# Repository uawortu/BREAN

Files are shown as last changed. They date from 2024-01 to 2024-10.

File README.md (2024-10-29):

# BREAN
## Custom esp32cam
Video : [I made a CUSTOM ESP32CAM！ - YouTube](https://www.youtube.com/watch?v=4ouxIVEyoTg)

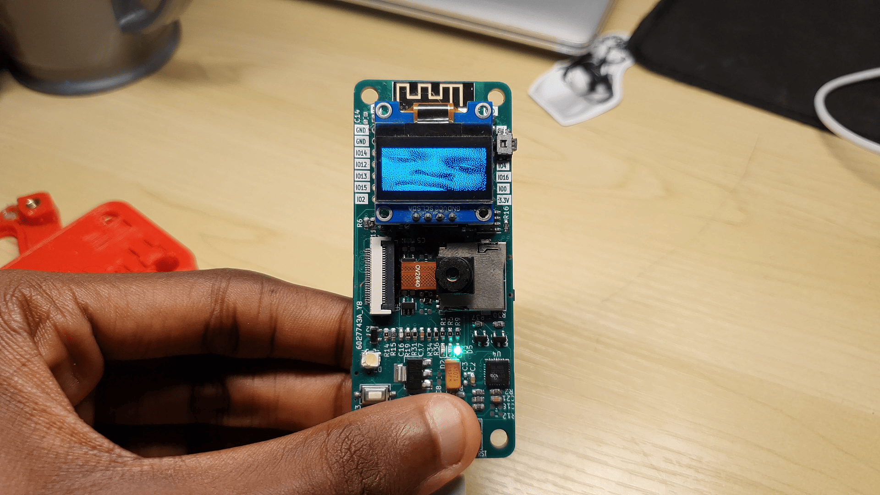
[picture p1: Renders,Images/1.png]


### Information provided
* 3dmodels
* Images and renders
* Gerber files
* My code and code used
* Print files
  
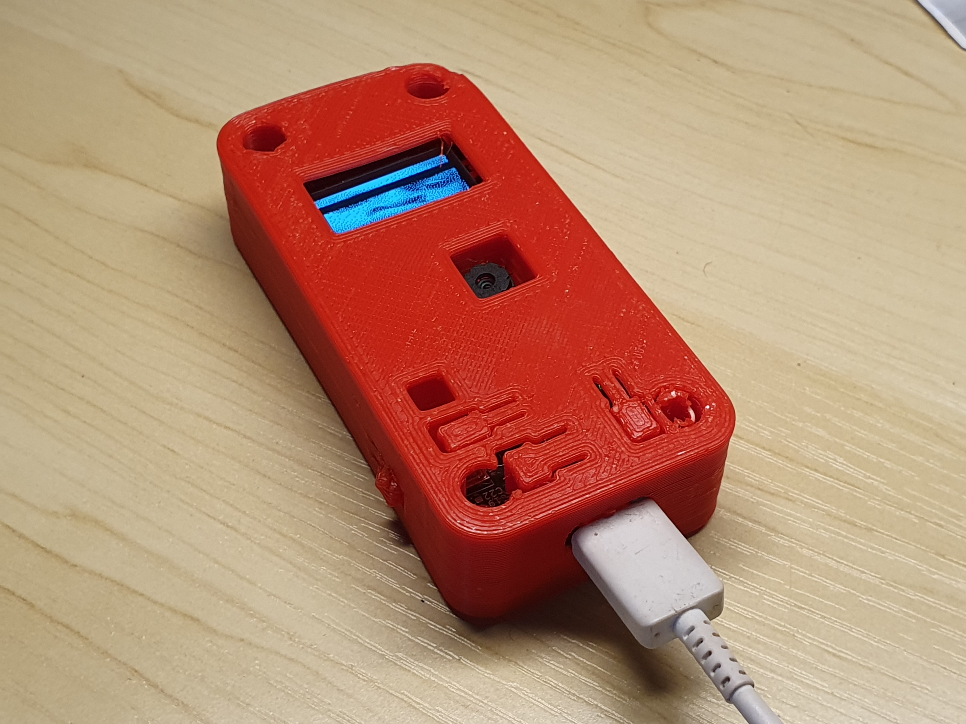
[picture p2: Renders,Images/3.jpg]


# I'll give a proper description in time

#### BOM/PART LIST 
[Google sheets](https://docs.google.com/spreadsheets/d/1bDLKCBJ3s3EqrjJLohymS0VN41cs3GhnOAAEiNUEGFg/edit?usp=sharing)
[CSV file download](https://github.com/user-attachments/files/17560012/BOM.csv)

##### BREAN=beans+bread

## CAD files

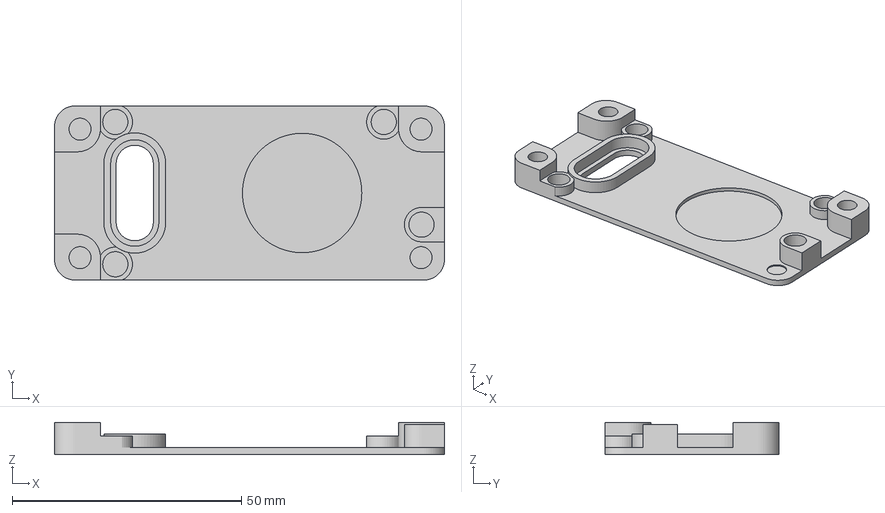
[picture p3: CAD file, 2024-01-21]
Hardware/Print files/espcam bottom plate.3mf
85.0 x 38.0 x 7.00 mm

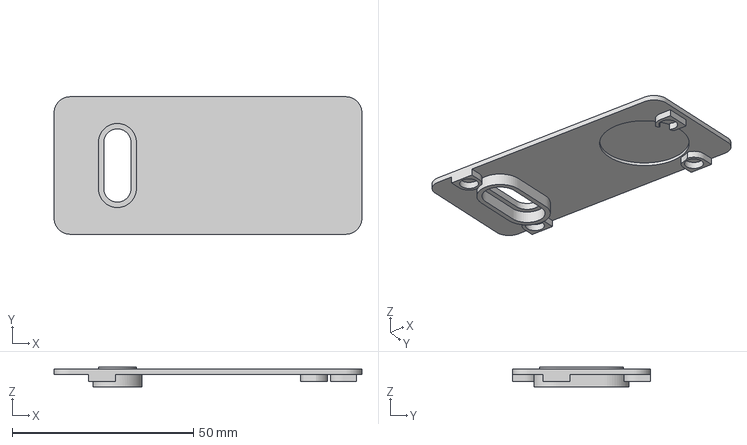
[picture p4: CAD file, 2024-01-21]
Hardware/Print files/power case top plate.3mf
85.0 x 38.0 x 5.50 mm

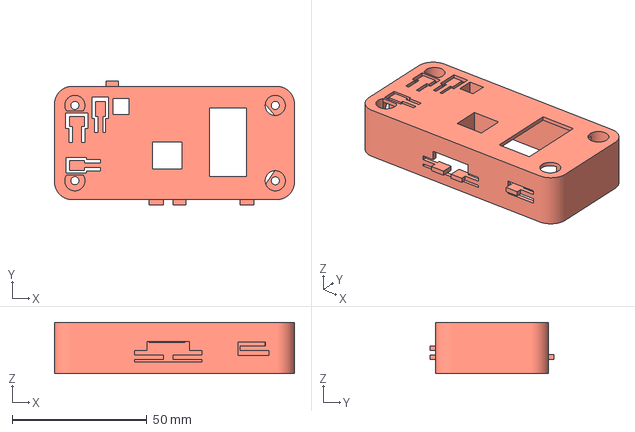
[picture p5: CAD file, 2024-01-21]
Hardware/Print files/espcam top casing.3mf
89.0 x 45.9 x 19.0 mm

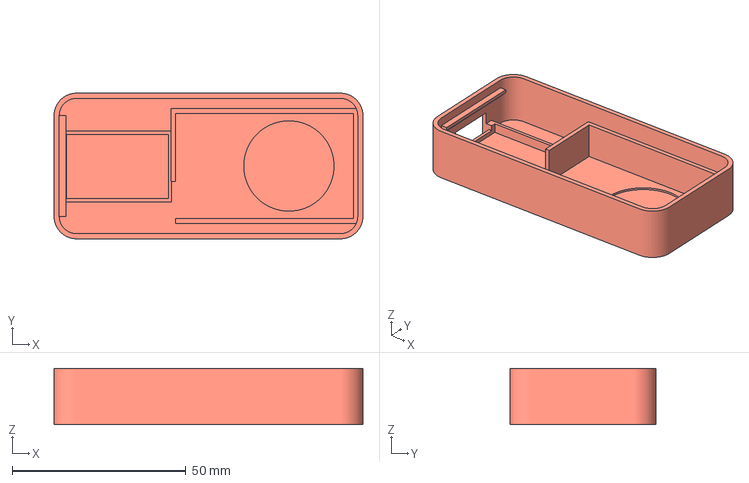
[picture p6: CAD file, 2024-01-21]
Hardware/Print files/power case bottom.3mf
89.0 x 42.0 x 16.2 mm

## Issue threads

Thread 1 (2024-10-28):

Parts List

ankushDhawan5812, 2024-10-28:
Hi, I was wanting to build off of your design to make a touch sensor based on multiple ESP32 cameras. Do you have the KiCAD files and a parts list I could reference? Thank you, I really enjoyed your project and YouTube videos!

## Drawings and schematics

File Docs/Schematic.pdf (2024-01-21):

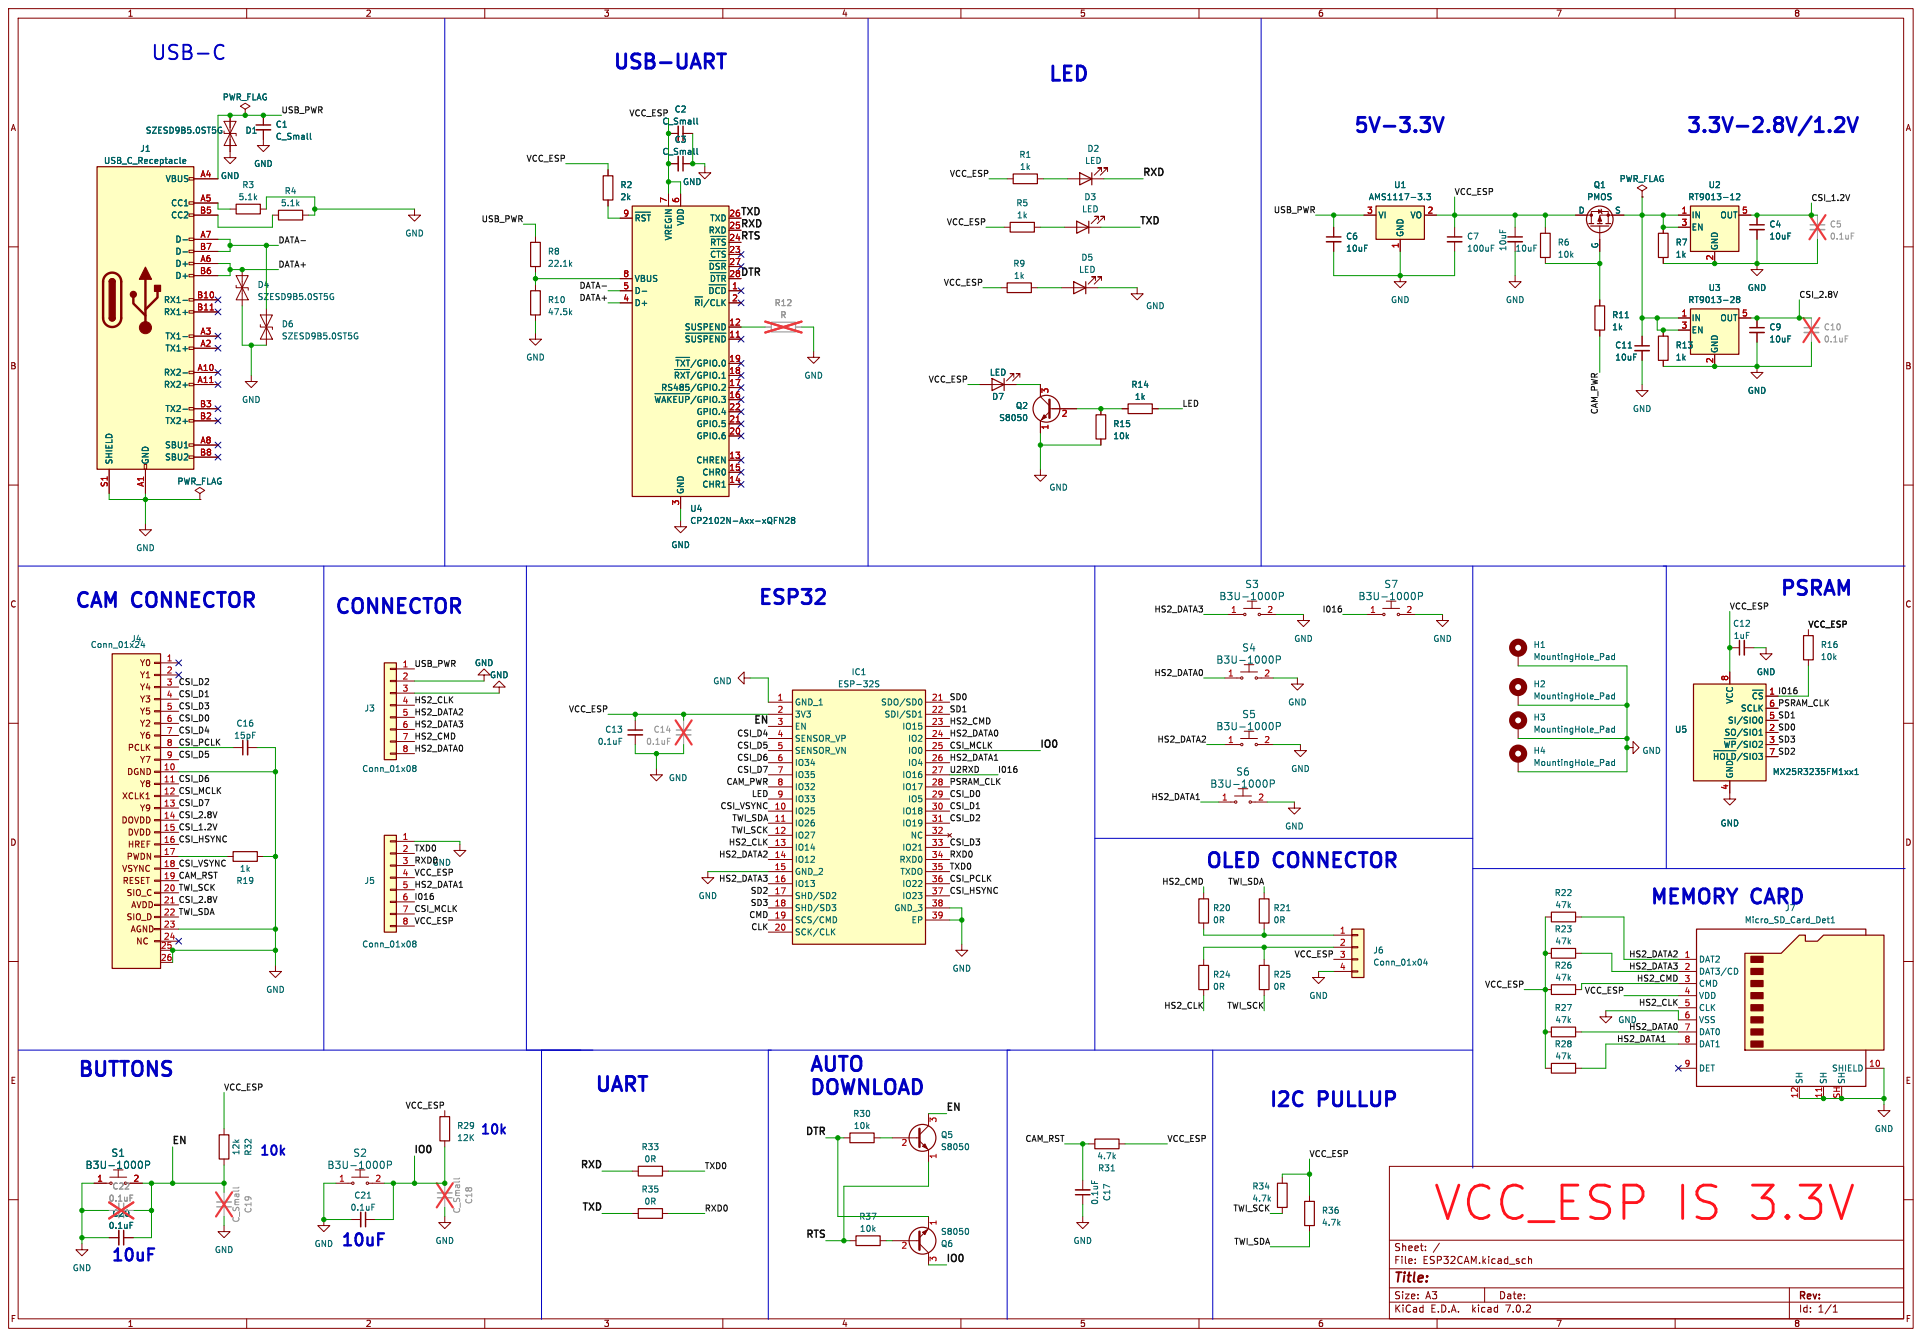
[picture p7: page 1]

7 VBUS 8 ~{RST} 9 U4 CP2102N-Axx-xQFN28 GND

1k GND
2 GPIO.6 20 GPIO.5 21 GPIO.4 22 ~{CTS} 23 ~{RTS} 24 RXD 25 TXD 26 ~{DSR} 27 ~{DTR} 28 GND

1 VO 2 VI 3 U1 AMS1117-3.3 GND GND 10uF 10uF C6

TXD
RXD
VCC_ESP RTS
~{DCD}1 ~{SUSPEND}11 SUSPEND 12 CHREN 13 CHR1 14 CHR0 15 ~{WAKEUP}/GPIO.3

U4 CP2102N-Axx-xQFN28 ~{DCD}1 ~{SUSPEND}11 SUSPEND 12 CHREN 13 CHR1 14 CHR0 15 ~{WAKEUP}/GPIO.3

IO13 16 SHD/SD2 17 SHD/SD3 18 SCS/CMD 19
SD3 SD2 CMD

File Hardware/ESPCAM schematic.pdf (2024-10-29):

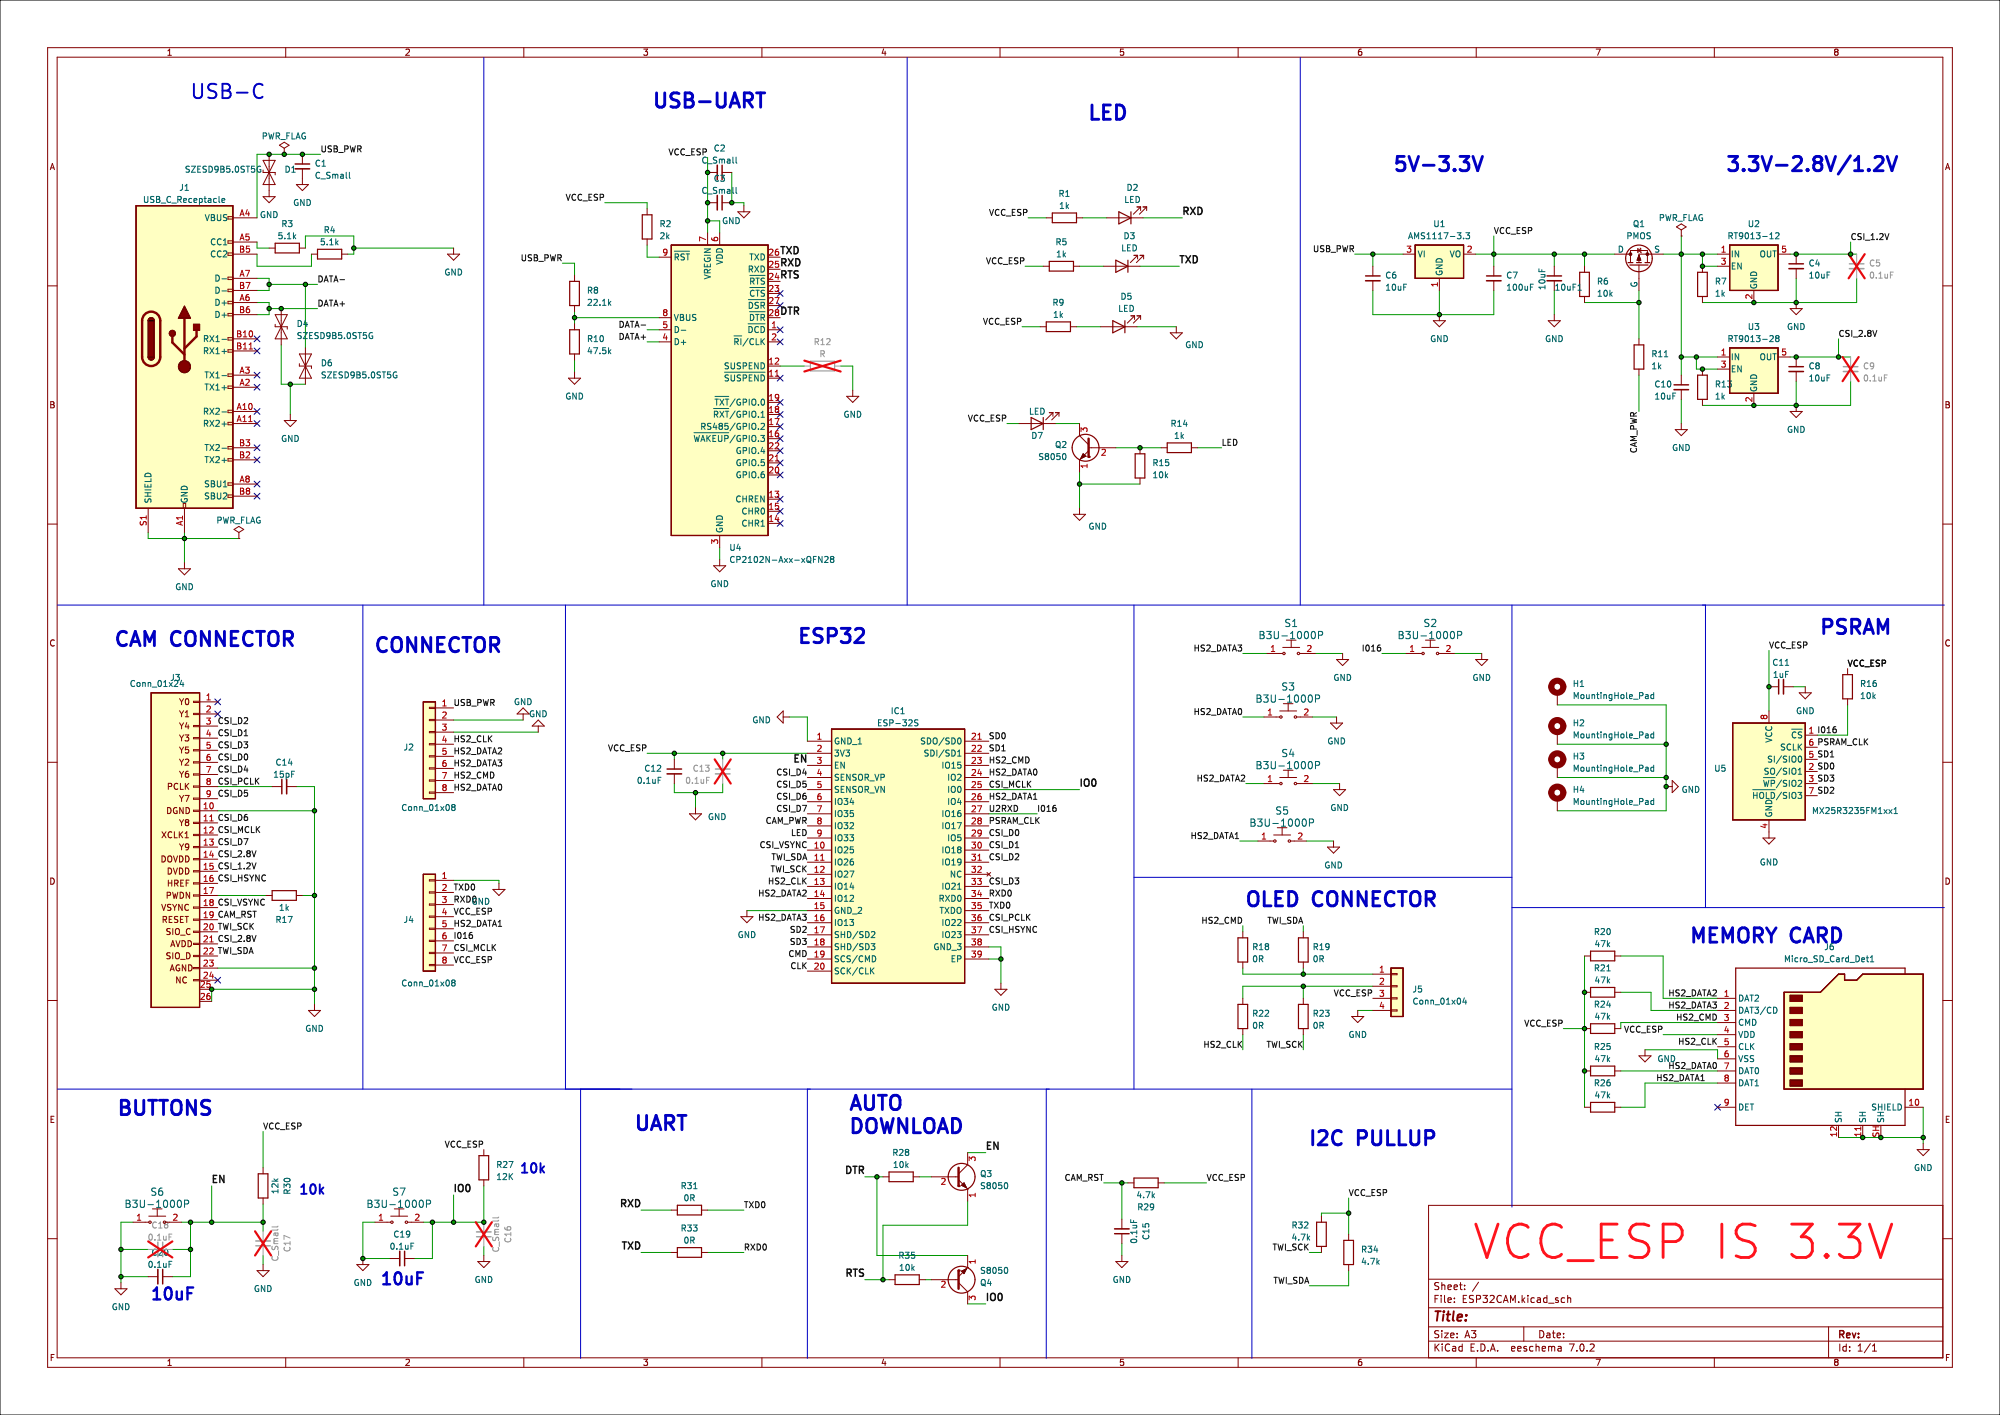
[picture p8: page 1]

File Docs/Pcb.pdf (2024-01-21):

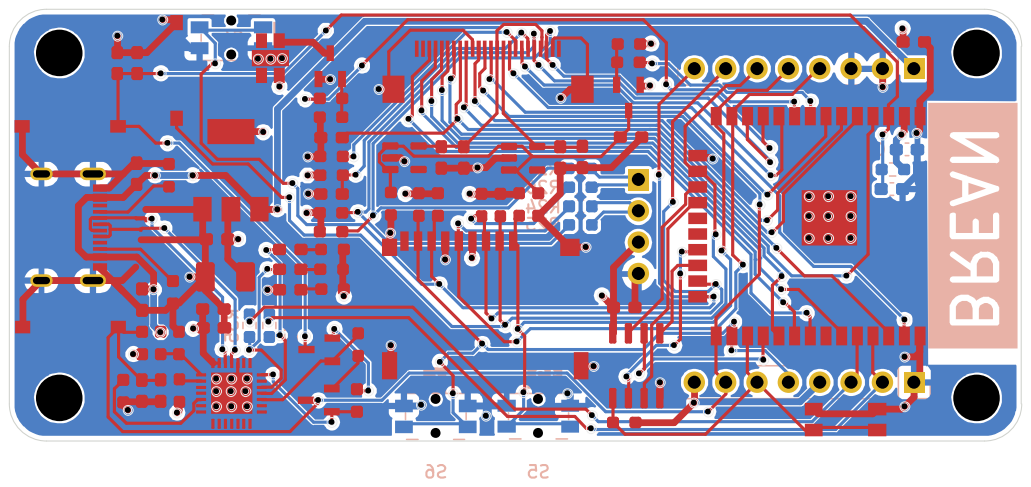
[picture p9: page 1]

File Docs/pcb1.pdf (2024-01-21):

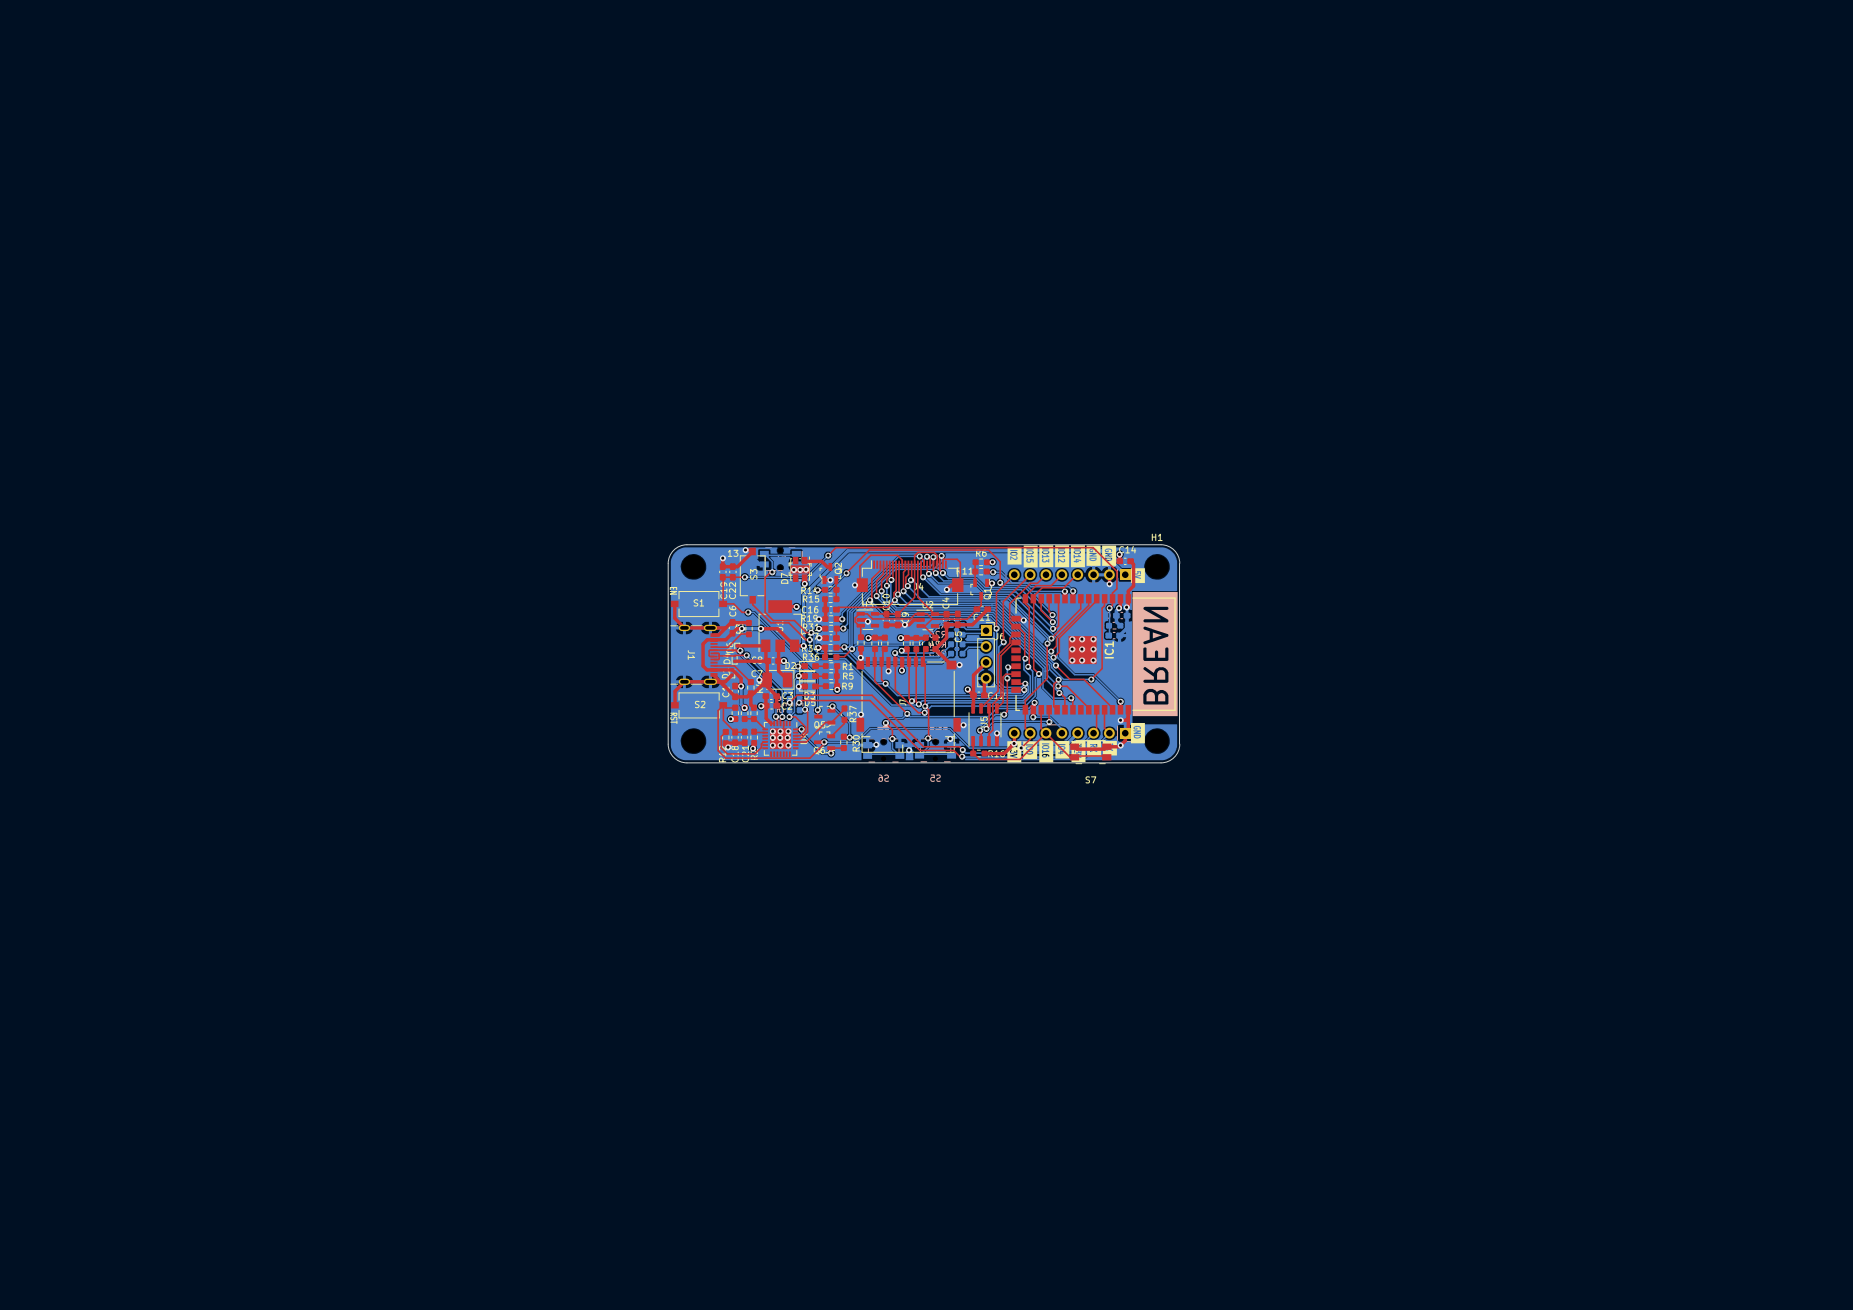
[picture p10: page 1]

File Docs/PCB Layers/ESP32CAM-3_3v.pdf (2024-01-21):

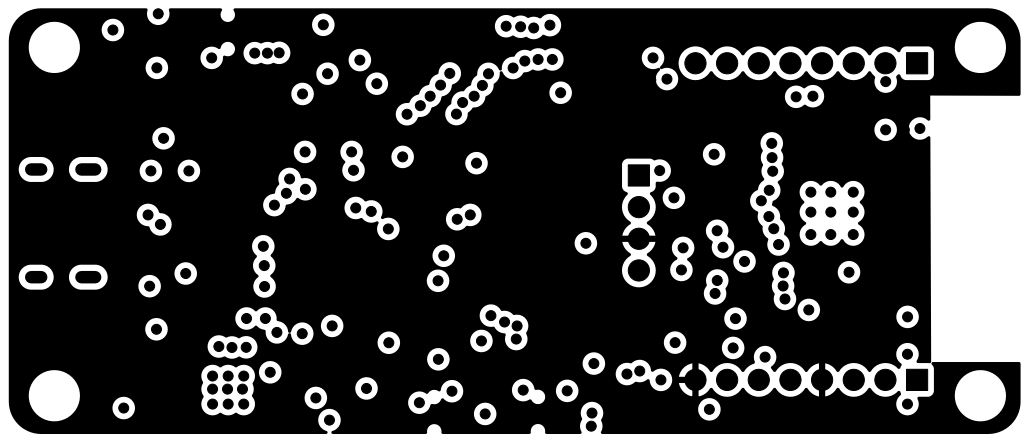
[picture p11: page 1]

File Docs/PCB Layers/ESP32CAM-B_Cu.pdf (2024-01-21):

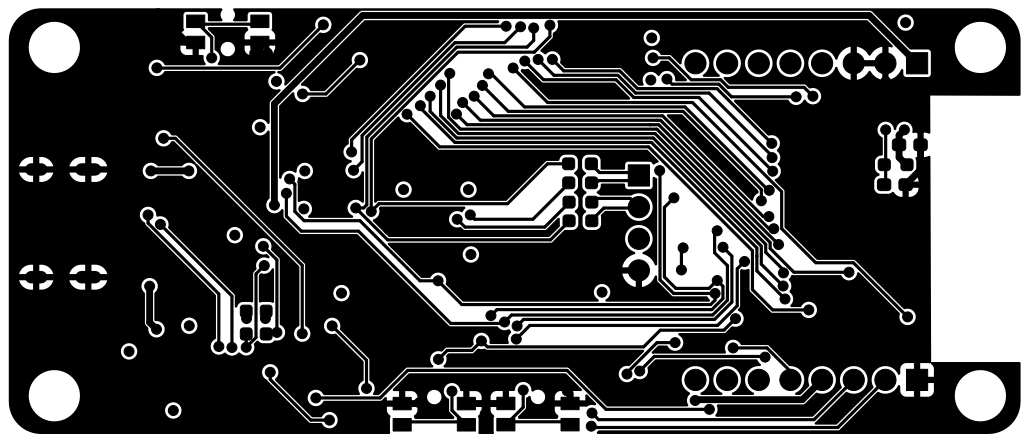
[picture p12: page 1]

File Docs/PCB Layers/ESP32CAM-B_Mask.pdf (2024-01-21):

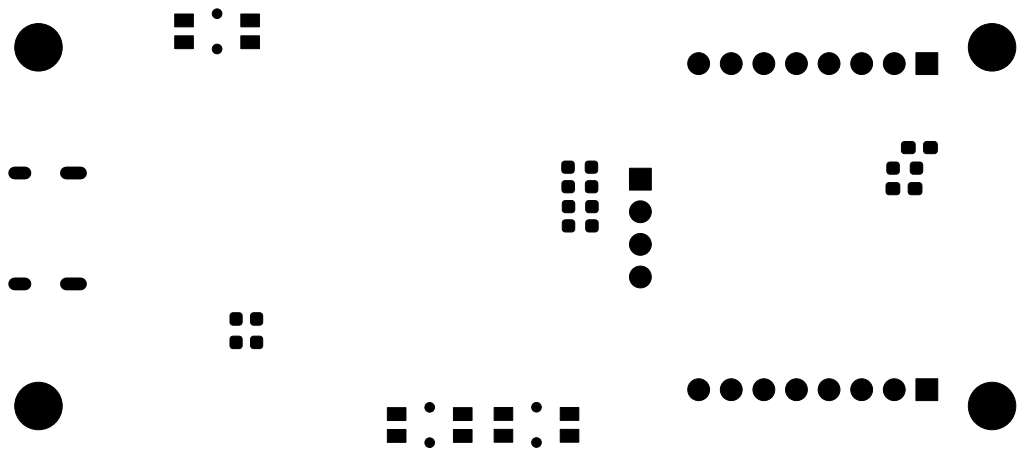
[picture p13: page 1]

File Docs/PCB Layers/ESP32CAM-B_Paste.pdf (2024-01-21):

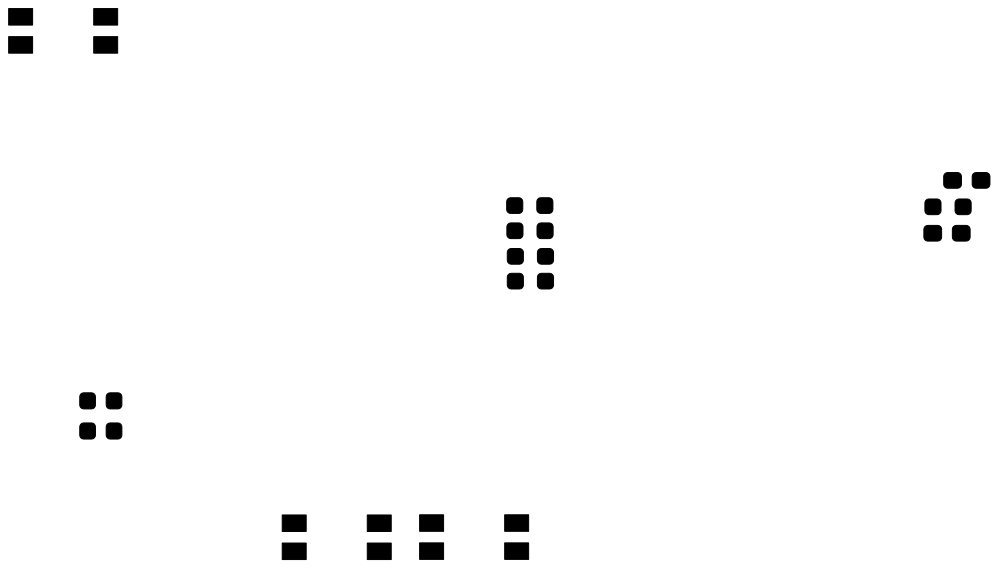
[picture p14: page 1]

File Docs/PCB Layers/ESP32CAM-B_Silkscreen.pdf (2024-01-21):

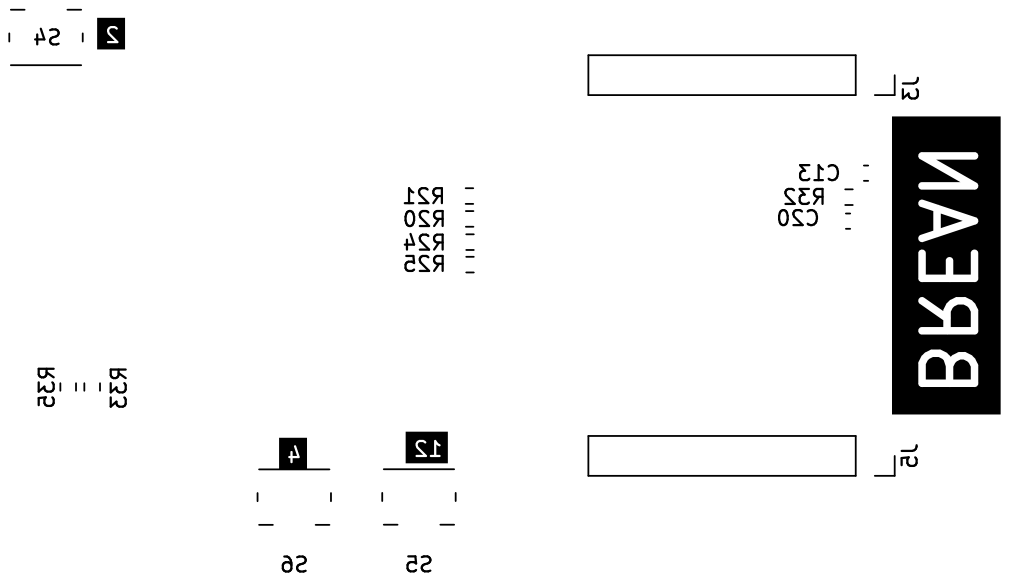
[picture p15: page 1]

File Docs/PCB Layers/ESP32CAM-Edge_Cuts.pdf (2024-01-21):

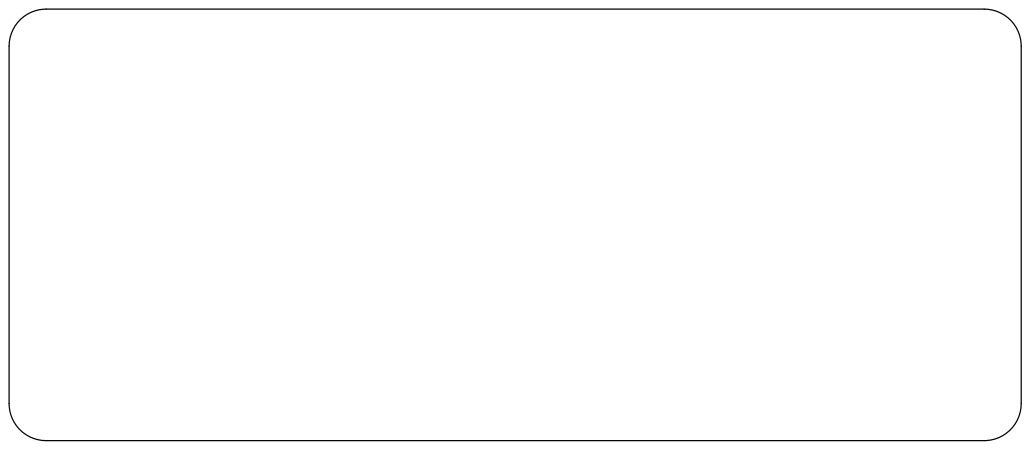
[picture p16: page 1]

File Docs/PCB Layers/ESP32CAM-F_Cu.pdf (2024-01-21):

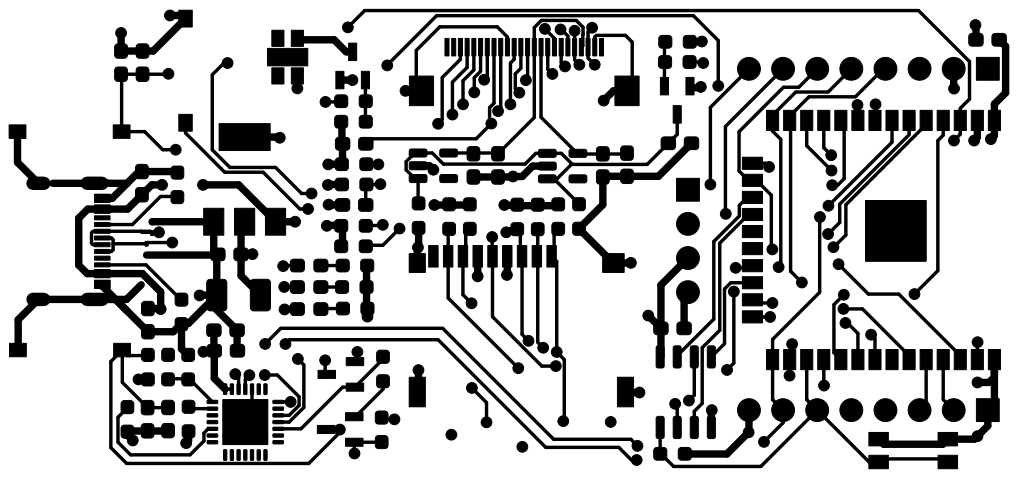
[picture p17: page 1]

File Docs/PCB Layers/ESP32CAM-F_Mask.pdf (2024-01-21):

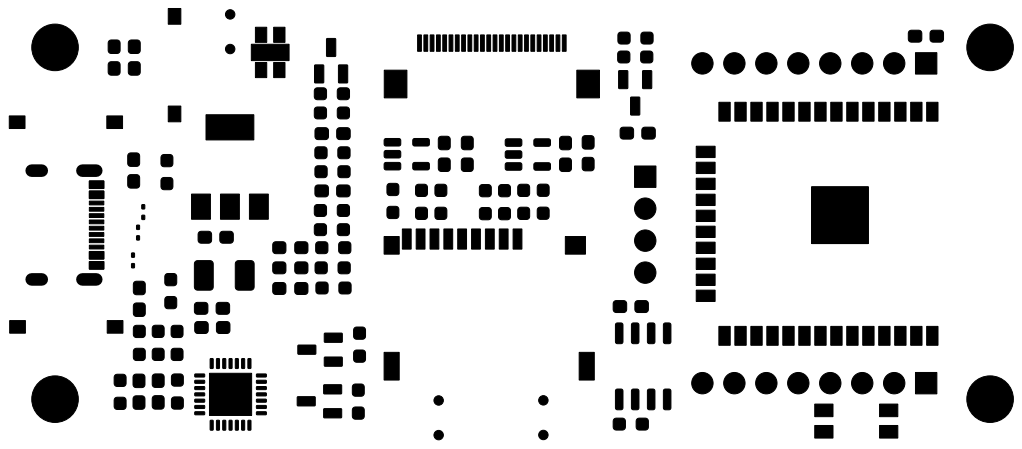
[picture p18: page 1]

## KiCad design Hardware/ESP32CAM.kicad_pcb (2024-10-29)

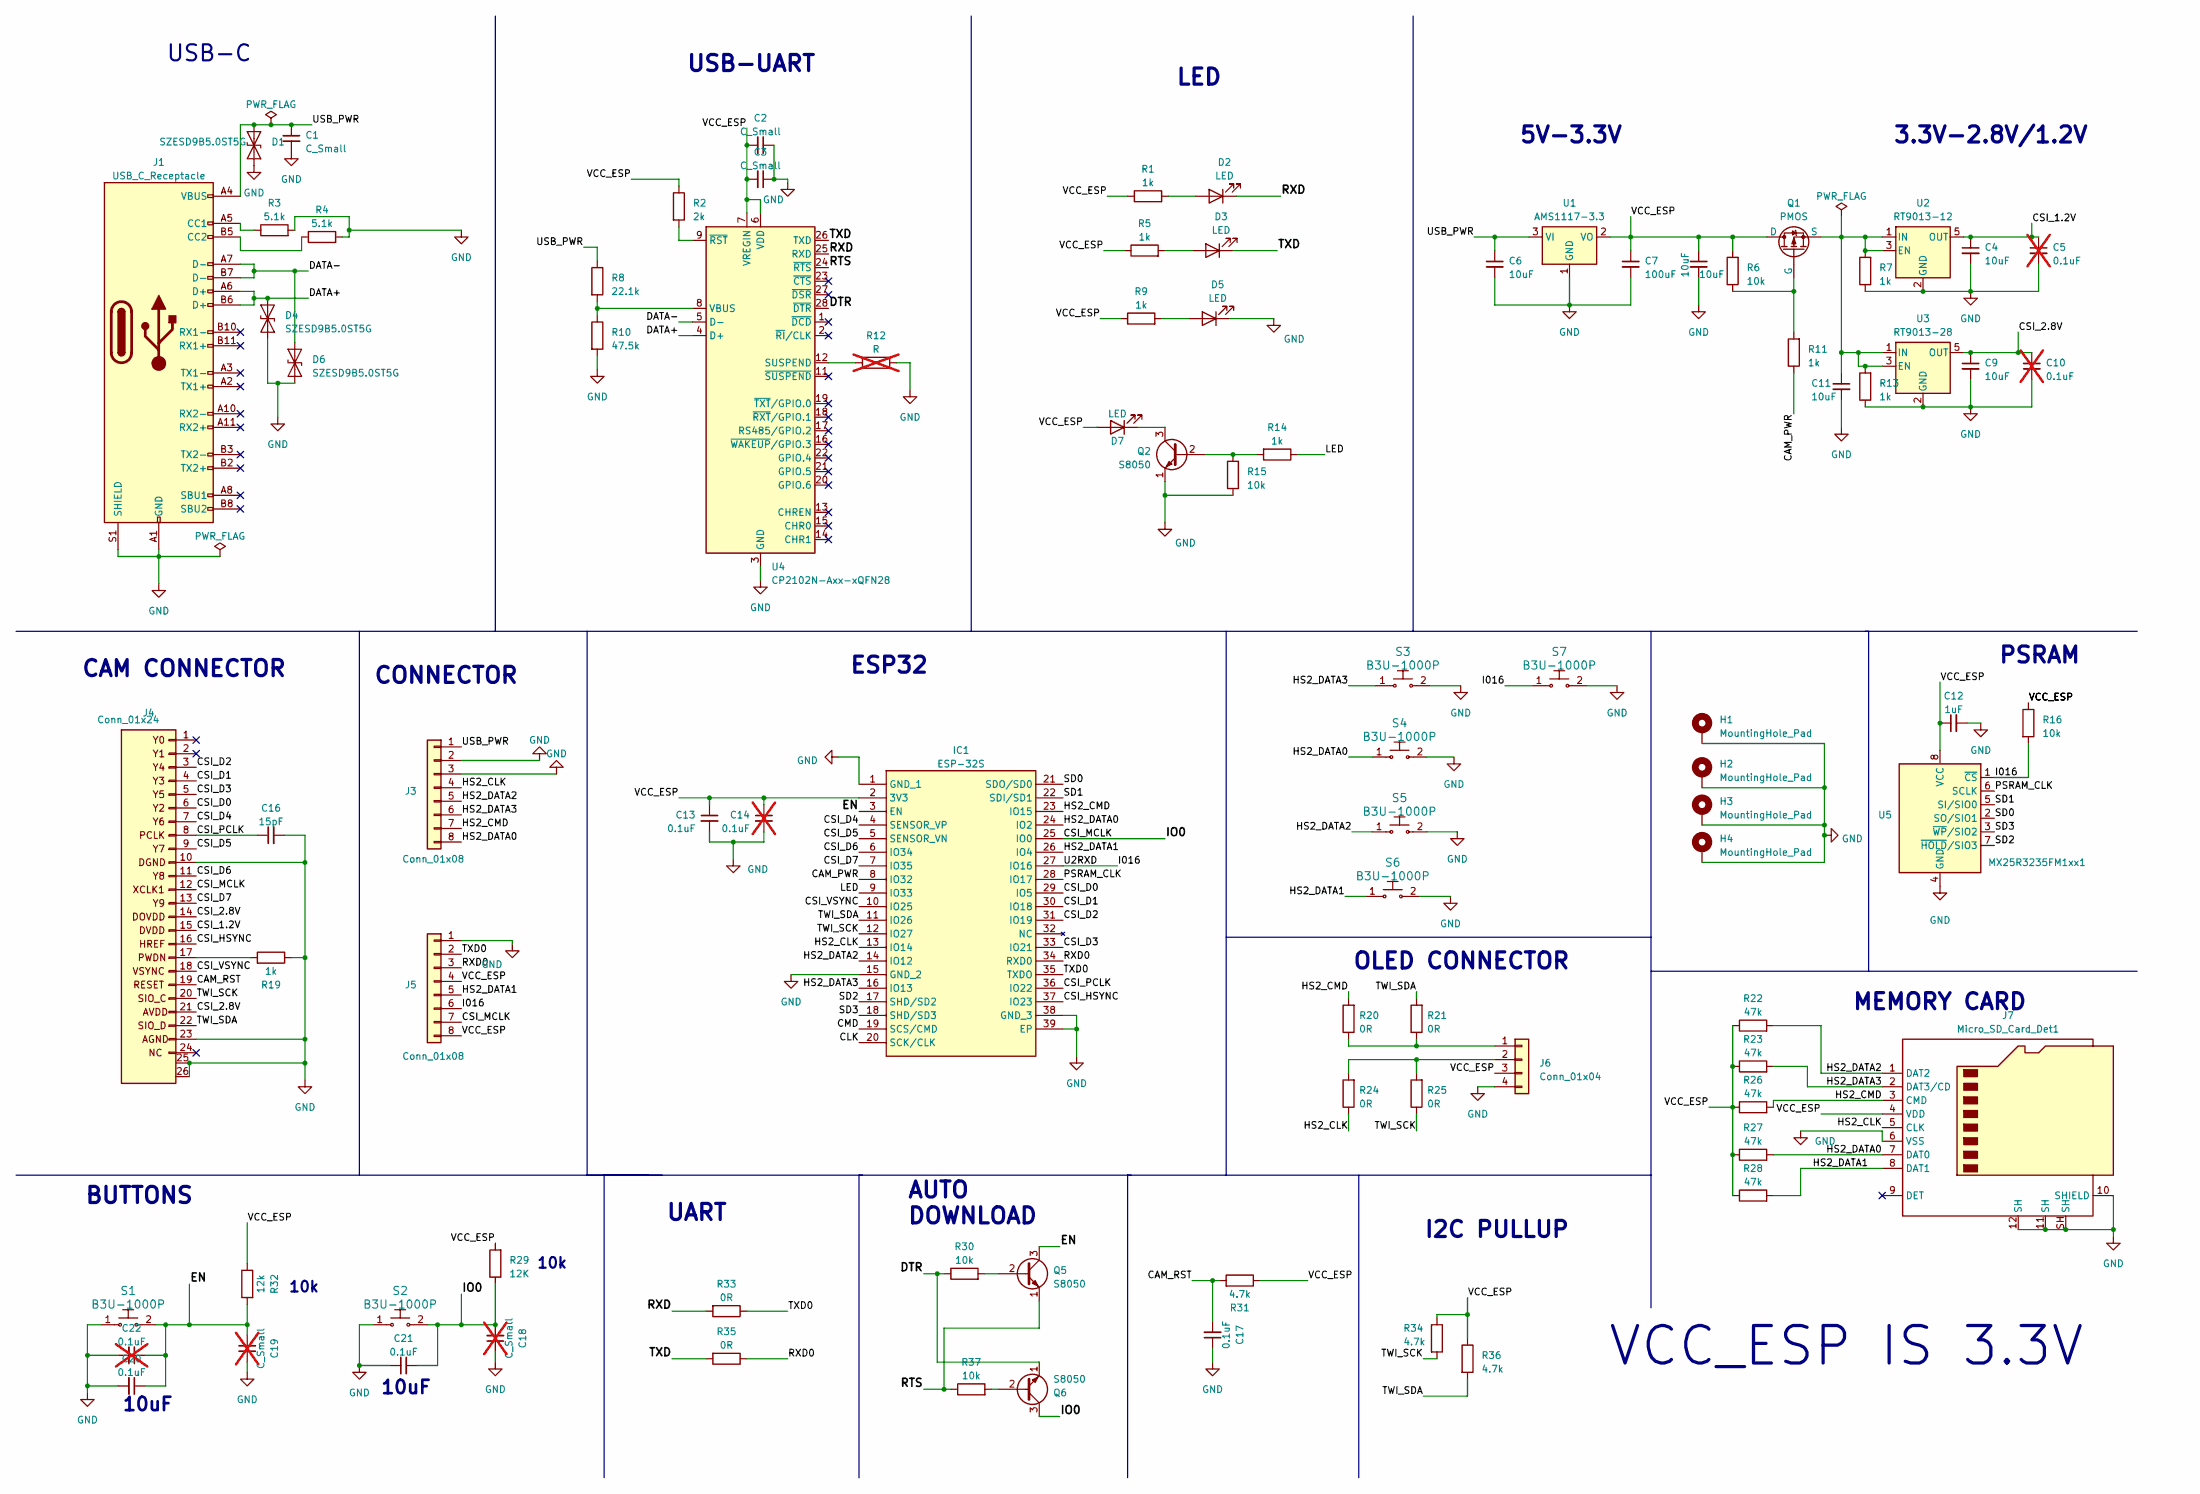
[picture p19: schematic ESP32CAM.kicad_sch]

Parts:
10uF: 10uF; C_0603_1608Metric_Pad1.08x0.95mm_HandSolder
C1, C2, C3: C_Small; C_0603_1608Metric_Pad1.08x0.95mm_HandSolder
C4, C6, C9, C11: 10uF; C_0603_1608Metric_Pad1.08x0.95mm_HandSolder
C5, C10, C14, C22: 0.1uF; C_0603_1608Metric_Pad1.08x0.95mm_HandSolder; not fitted
C7: 100uF; CP_EIA-3528-15_AVX-H_Pad1.50x2.35mm_HandSolder
C12: 1uF; C_0603_1608Metric_Pad1.08x0.95mm_HandSolder
C13, C17, C20, C21: 0.1uF; C_0603_1608Metric_Pad1.08x0.95mm_HandSolder
C16: 15pF; C_0603_1608Metric_Pad1.08x0.95mm_HandSolder
C18, C19: C_Small; C_0603_1608Metric_Pad1.08x0.95mm_HandSolder; not fitted
D1, D4, D6: SZESD9B5.0ST5G; D_SOD-923
D2, D3, D5: LED; LED_0603_1608Metric_Pad1.05x0.95mm_HandSolder
D7: LED; LED_Kingbright_AAA3528ESGCT
H1, H2, H3, H4: MountingHole_Pad; MountingHole_3.7mm
IC1: ESP-32S; ESP32S; Manufacturer_Part_Number ESP-32S; Mouser Part Number N/A
J1: USB_C_Receptacle; USB_C_Receptacle_GCT_USB4105-xx-A_16P_TopMnt_Horizontal
J3, J5: Conn_01x08; PinHeader_1x08_P2.54mm_Vertical
J4: Conn_01x24; Hirose_FH12-24S-0.5SH_1x24-1MP_P0.50mm_Horizontal
J6: Conn_01x04; PinSocket_1x04_P2.54mm_Vertical
J7: Micro_SD_Card_Det1; J_SD_Card-micro_socket_A
Q1: PMOS; SOT-23-3
Q2, Q5, Q6: S8050; SOT-23-3
R1, R5, R7, R9, R11, R13, R14, R19: 1k; R_0603_1608Metric_Pad0.98x0.95mm_HandSolder
R2: 2k; R_0603_1608Metric_Pad0.98x0.95mm_HandSolder
R3, R4: 5.1k; R_0603_1608Metric_Pad0.98x0.95mm_HandSolder
R6, R15, R16, R30, R37: 10k; R_0603_1608Metric_Pad0.98x0.95mm_HandSolder
R8: 22.1k; R_0603_1608Metric_Pad0.98x0.95mm_HandSolder
R10: 47.5k; R_0603_1608Metric_Pad0.98x0.95mm_HandSolder
R12: R; R_0603_1608Metric_Pad0.98x0.95mm_HandSolder; not fitted
R20, R21, R24, R25, R33, R35: 0R; R_0603_1608Metric_Pad0.98x0.95mm_HandSolder
R22, R23, R26, R27, R28: 47k; R_0603_1608Metric_Pad0.98x0.95mm_HandSolder
R29: 12K; R_0603_1608Metric_Pad0.98x0.95mm_HandSolder
R31, R34, R36: 4.7k; R_0603_1608Metric_Pad0.98x0.95mm_HandSolder
R32: 12k; R_0603_1608Metric_Pad0.98x0.95mm_HandSolder
S1, S2, S3: B3U-1000P; SW_Tactile_SPST_NO_Straight_CK_PTS636Sx25SMTRLFS; MPN B3U-1000P; Digi-Key_PN SW1020CT-ND
S4, S5, S6, S7: B3U-1000P; Panasonic_EVQPUM_EVQPUD; MPN B3U-1000P; Digi-Key_PN SW1020CT-ND
U1: AMS1117-3.3; SOT-223-3_TabPin2
U2: RT9013-12; SOT-23-5
U3: RT9013-28; SOT-23-5
U4: CP2102N-Axx-xQFN28; QFN-28-1EP_5x5mm_P0.5mm_EP3.35x3.35mm
U5: MX25R3235FM1xx1; SOP-8_3.9x4.9mm_P1.27mm

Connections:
/CAM_PWR: IC1.8 (IO32), R11.1
/CAM_RST: C17.2, J4.19, R31.2
/CLK: IC1.20 (SCK/CLK)
/CMD: IC1.19 (SCS/CMD)
/CSI_1.2V: C4.1, C5.1, J4.15, U2.5 (OUT)
/CSI_2.8V: C9.1, C10.1, J4.14, J4.21, U3.5 (OUT)
/CSI_D0: IC1.29 (IO5), J4.6
/CSI_D1: IC1.30 (IO18), J4.4
/CSI_D2: IC1.31 (IO19), J4.3
/CSI_D3: IC1.33 (IO21), J4.5
/CSI_D4: IC1.4 (SENSOR_VP), J4.7
/CSI_D5: IC1.5 (SENSOR_VN), J4.9
/CSI_D6: IC1.6 (IO34), J4.11
/CSI_D7: IC1.7 (IO35), J4.13
/CSI_HSYNC: IC1.37 (IO23), J4.16
/CSI_MCLK: C18.2, C21.1, IC1.25 (IO0), J4.12, J5.7, Q6.3 (C), R29.1, S2.2
/CSI_PCLK: C16.1, IC1.36 (IO22), J4.8
/CSI_VSYNC: IC1.10 (IO25), J4.18
/DATA+: D4.2 (A2), J1.A6 (D+), J1.B6 (D+), U4.4 (D+)
/DATA-: D6.2 (A2), J1.A7 (D-), J1.B7 (D-), U4.5 (D-)
/DTR: Q6.1 (E), R30.1, U4.28 (~DTR)
/EN: C19.2, C20.1, C22.1, IC1.3 (EN), Q5.3 (C), R32.2, S1.2
/HS2_CLK: IC1.13 (IO14), J3.4, J7.5 (CLK), R24.1
/HS2_CMD: IC1.23 (IO15), J3.7, J7.3 (CMD), R20.2, R26.2
/HS2_DATA0: IC1.24 (IO2), J3.8, J7.7 (DAT0), R27.2, S4.1
/HS2_DATA1: IC1.26 (IO4), J5.5, J7.8 (DAT1), R28.2, S6.1
/HS2_DATA2: IC1.14 (IO12), J3.5, J7.1 (DAT2), R22.2, S5.1
/HS2_DATA3: IC1.16 (IO13), J3.6, J7.2 (DAT3/CD), R23.2, S3.1
/I016: IC1.27 (IO16), J5.6, R16.2, S7.1, U5.1 (~CS)
/LED: IC1.9 (IO33), R14.1
/PSRAM_CLK: IC1.28 (IO17), U5.6 (SCLK)
/RTS: Q5.1 (E), R37.1, U4.24 (~RTS)
/RXD: D2.1 (K), R33.2, U4.25 (RXD)
/RXD0: IC1.34 (RXD0), J5.3, R35.1
/SD0: IC1.21 (SDO/SD0), U5.2 (SO/SIO1)
/SD1: IC1.22 (SDI/SD1), U5.5 (SI/SIO0)
/SD2: IC1.17 (SHD/SD2), U5.7 (~HOLD/SIO3)
/SD3: IC1.18 (SHD/SD3), U5.3 (~WP/SIO2)
/TWI_SCK: IC1.12 (IO27), J4.20, R25.1, R34.2
/TWI_SDA: IC1.11 (IO26), J4.22, R21.2, R36.2
/TXD: D3.1 (K), R35.2, U4.26 (TXD)
/TXD0: IC1.35 (TXDO), J5.2, R33.1
/USB_PWR: C1.1, C6.1, D1.2 (A2), J1.A4 (VBUS), J1.A9 (VBUS), J1.B4 (VBUS), J1.B9 (VBUS), J3.1, R8.1, U1.3 (VI)
/VCC_ESP: 10uF.1, C2.2, C3.2, C7.1, C12.1, C13.1, C14.1, D7.2 (A), IC1.2 (3V3), J5.4, J5.8, J6.3, J7.4 (VDD), Q1.1 (D), R1.1, R2.1, R5.1, R6.2, R9.1, R16.1, R22.1, R23.1, R26.1, R27.1, R28.1, R29.2, R31.1, R32.1, R34.1, R36.1, U1.2 (VO), U4.6 (VDD), U4.7 (VREGIN), U5.8 (VCC); also elsewhere on the board
GND: 10uF.2, C1.2, C2.1, C3.1, C4.2, C5.2, C6.2, C7.2, C9.2, C10.2, C11.2, C12.2, C13.2, C14.2, C16.2, C17.1, C18.1, C19.1, C20.2, C21.2, C22.2, D1.1 (A1), D4.1 (A1), D5.1 (K), D6.1 (A1), H1.1, H2.1, H3.1, H4.1, IC1.1 (GND_1), IC1.15 (GND_2), IC1.38 (GND_3), IC1.39 (EP), J1.A1 (GND), J1.A12 (GND), J1.B1 (GND), J1.B12 (GND), J1.S1 (SHIELD), J3.2, J3.3, J4.10, J4.23, J4.25 (GND), J4.26 (GND), J5.1, J6.4, J7.6 (VSS), J7.10 (SHIELD), J7.11 (SH), J7.12 (SH), J7.SH, Q2.1 (E), R3.2, R4.2, R7.1, R10.2, R12.2, R13.1, R15.1, R19.1, S1.1, S2.1, S3.2, S4.2, S5.2, S6.2, S7.2, U1.1 (GND), U2.2 (GND), U3.2 (GND), U4.3 (GND), U4.29 (GND), U5.4 (GND); also elsewhere on the board
unnamed: C11.1, Q1.3 (S), R7.2, R13.2, U2.1 (IN), U2.3 (EN), U3.1 (IN), U3.3 (EN)
unnamed: D2.2 (A), R1.2
unnamed: D3.2 (A), R5.2
unnamed: D5.2 (A), R9.2
unnamed: D7.1 (K), Q2.3 (C)
unnamed: J1.A5 (CC1), R3.1
unnamed: J1.B5 (CC2), R4.1
unnamed: J4.17, R19.2
unnamed: J6.1, R20.1, R21.1
unnamed: J6.2, R24.2, R25.2
unnamed: Q1.2 (G), R6.1, R11.2
unnamed: Q2.2 (B), R14.2, R15.2
unnamed: Q5.2 (B), R30.2
unnamed: Q6.2 (B), R37.2
unnamed: R12.1, U4.12 (SUSPEND)
unnamed: R8.2, R10.1, U4.8 (VBUS)
unnamed: R2.2, U4.9 (~RST)

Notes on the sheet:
VCC_ESP IS 3.3V
5V-3.3V
CAM CONNECTOR
10uF
3.3V-2.8V/1.2V
LED
ESP32
USB-UART
OLED CONNECTOR
10k
UART
BUTTONS
PSRAM
CONNECTOR
I2C PULLUP
MEMORY CARD
USB-C
AUTO DOWNLOAD

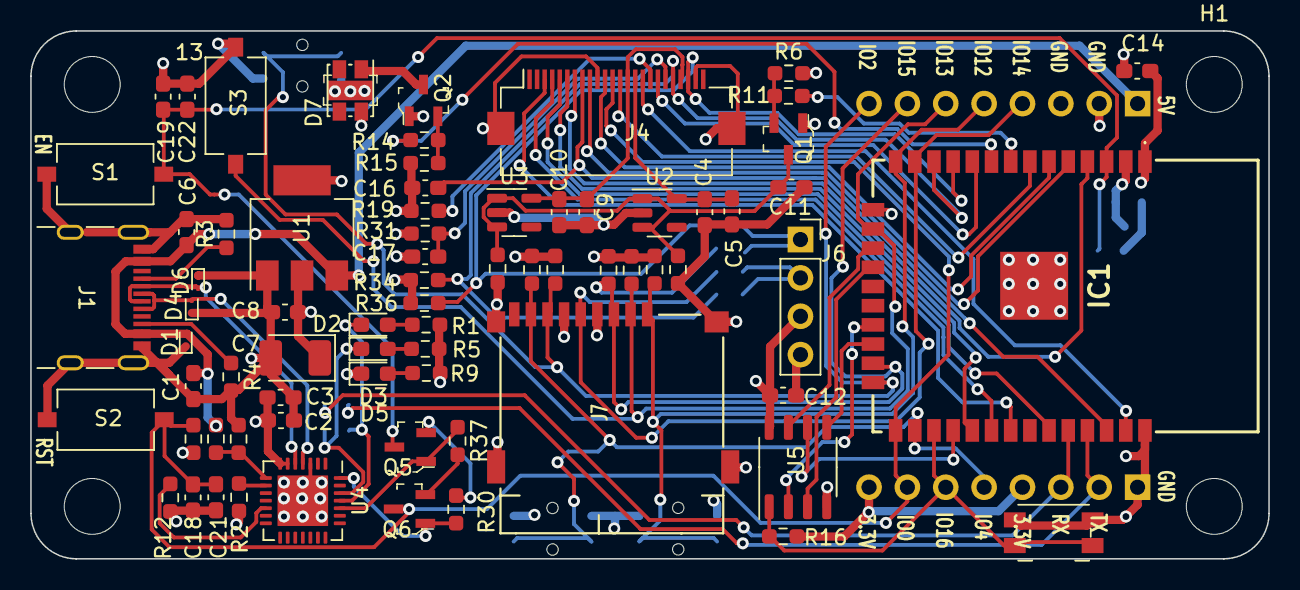
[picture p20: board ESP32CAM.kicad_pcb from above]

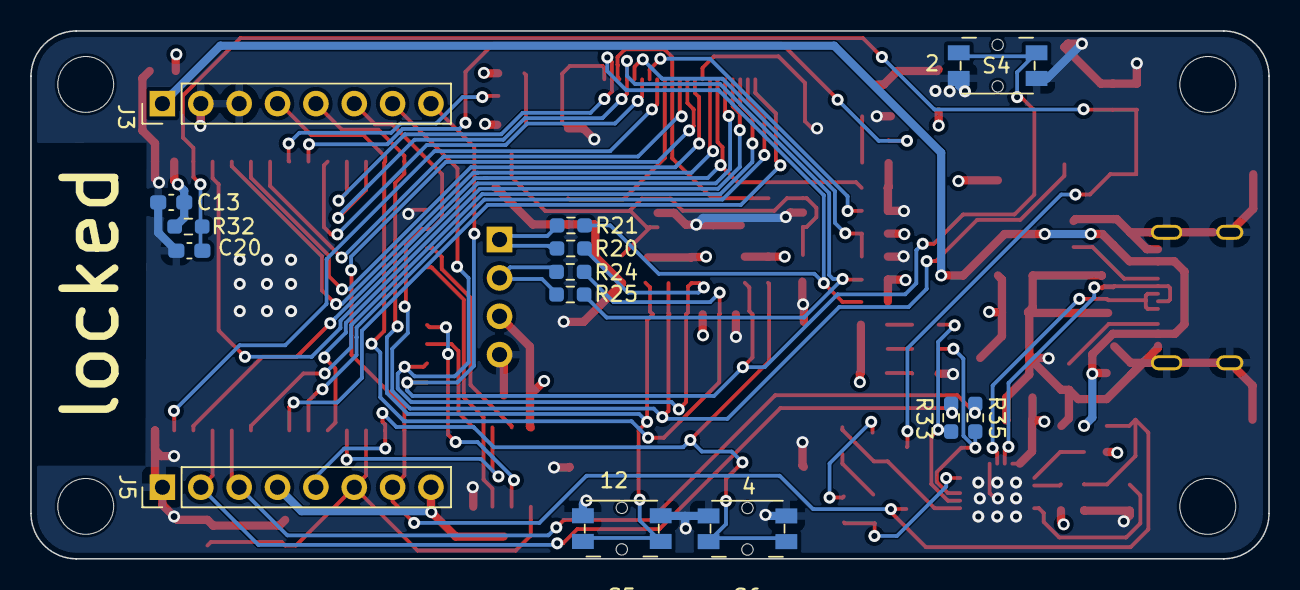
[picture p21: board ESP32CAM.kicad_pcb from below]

Board: 4 copper layers, 82.0 x 35.0 mm, 90 parts (14 on the bottom side), 60 nets.

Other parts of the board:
C8: 10uF; C_0603_1608Metric_Pad1.08x0.95mm_HandSolder

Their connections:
/VCC_ESP: C8.1; also elsewhere on the board
GND: C8.2; also elsewhere on the board

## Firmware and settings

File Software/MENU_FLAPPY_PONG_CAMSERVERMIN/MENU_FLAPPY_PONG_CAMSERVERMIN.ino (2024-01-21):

#include <U8g2lib.h>
#include "images.h"
#include "fontovi.h"
#include "functions.h"




U8G2_SSD1306_128X64_NONAME_F_HW_I2C u8g2(U8G2_R0, U8X8_PIN_NONE, SCREEN_SCL, SCREEN_SDA);



void FLAPPY1(void);
void PONG1(void);
void CAMERA1(void);
void YOUTUBE1(void);
void WIFI1(void);




void (*FUNCTION[])(void) = {
  FLAPPY1,
  PONG1,
  CAMERA1,
  YOUTUBE1,
  WIFI1
};


const unsigned char FACE [] PROGMEM ={
 0xdd,0xff,0xff,0xff,0xff,0xff,0xff,0xff,0xff,0xff,0xff,0xff,0x6d,0xab,0xaa,
 0x1a,0x6b,0xb5,0xfd,0xff,0xff,0xff,0xff,0xff,0xff,0xff,0xdf,0xaa,0x56,0x55,
 0x55,0xb5,0xf6,0xff,0xaf,0xdd,0xff,0xff,0xff,0xff,0xff,0xff,0xf6,0xff,0xbd,
 0xaa,0xaa,0x2a,0x5d,0x6d,0xfb,0xf7,0xfd,0xff,0xff,0xff,0xff,0xdf,0x7f,0xb7,
 0x6b,0xab,0x92,0xea,0xeb,0xdf,0xd6,0x7e,0xff,0xff,0xff,0xff,0xff,0xfd,0xdf,
 0x7f,0xdf,0x2a,0xa5,0x94,0xbd,0xb5,0xfd,0xdb,0xd7,0xfe,0xff,0xff,0xdf,0xff,
 0xf6,0xed,0xb5,0x55,0x2a,0x65,0xf7,0x6e,0xb7,0x6e,0xbd,0xdb,0xfd,0xbf,0xf7,
 0xef,0xff,0xbf,0x6f,0xd7,0x52,0x59,0xad,0xd5,0xee,0x5b,0x6b,0xed,0x6f,0xf7,
 0xff,0xfb,0xbf,0xf6,0xfa,0xba,0x4a,0x52,0x7b,0x7f,0xbb,0xd6,0x4a,0x5b,0xfd,
 0xff,0xff,0x7e,0xeb,0xaf,0xaf,0x57,0x95,0xaa,0xd6,0xaa,0xef,0xbb,0x54,0xb2,
 0xab,0x7e,0xfb,0xff,0xff,0xfa,0xfe,0x7a,0xab,0x4a,0xad,0xed,0x7a,0x6f,0x93,
 0x44,0xea,0xeb,0xdf,0x6f,0xbb,0xdf,0xab,0xaf,0xaa,0x54,0x5b,0xdb,0xdf,0xbb,
 0x2a,0x55,0x55,0xbd,0xf7,0xfe,0xef,0x76,0x7f,0xf5,0xad,0xaa,0xb6,0xb6,0xea,
 0xee,0x4a,0x88,0xa8,0xf6,0xbe,0xab,0xba,0xdd,0xea,0xaf,0xaa,0xaa,0xd5,0xaa,
 0xda,0xbf,0xaa,0x52,0x4a,0xad,0xfb,0xfd,0xd7,0xb6,0x57,0xb5,0xdb,0xaa,0x55,
 0x55,0xab,0xa2,0x05,0x85,0x54,0xd5,0xae,0x57,0xba,0x55,0x5d,0x6b,0xb5,0xaa,
 0xaa,0xfe,0xff,0x7f,0x69,0x28,0x21,0x75,0x7f,0xd5,0x4a,0xaa,0xd2,0xd6,0xae,
 0x55,0x55,0x91,0xfa,0xff,0x96,0x22,0x4a,0xd5,0xab,0x2a,0x95,0x90,0x2a,0xa9,
 0x55,0x95,0x57,0x4a,0x02,0x92,0x2a,0x49,0xa9,0x7a,0xff,0xaa,0x20,0x45,0x40,
 0x4a,0xaa,0xaa,0xbf,0x52,0x55,0x24,0x51,0x12,0x52,0xed,0xab,0x4a,0x0a,0x10,
 0x0a,0x90,0x44,0x54,0xef,0x8a,0x0a,0x09,0x84,0x54,0xa5,0xb6,0xbf,0x15,0xa0,
 0x84,0xa0,0x4a,0x29,0x29,0xff,0xb6,0x22,0xa2,0x2a,0xaa,0x54,0xfb,0x6f,0x49,
 0x05,0x20,0x04,0x20,0x52,0x55,0xff,0x55,0x4d,0x08,0x52,0x78,0xdb,0xdd,0xbf,
 0x12,0x90,0x04,0x51,0x95,0x84,0xa0,0xff,0xaf,0xaa,0xa5,0x54,0xe7,0x76,0xff,
 0xef,0x85,0x04,0x50,0x84,0x54,0x55,0x4a,0xdf,0x7f,0x55,0xaa,0xfb,0xbb,0xdb,
 0xf5,0xbf,0x2a,0x20,0x05,0xa9,0xaa,0x92,0xa4,0xf7,0xdf,0xff,0xff,0xff,0xfe,
 0xbe,0xff,0x7b,0x0b,0x09,0x50,0x52,0x95,0x14,0x11,0xff,0xfb,0xdf,0xff,0xdf,
 0xaf,0xeb,0xfe,0xdf,0x55,0xa0,0x8a,0x2a,0xa9,0xa2,0x44,0xff,0xff,0xff,0xbd,
 0xfb,0xfd,0xfe,0xbf,0x7f,0x2f,0x0a,0x55,0xff,0x42,0x4a,0x90,0xff,0xff,0xff,
 0xff,0x7f,0xd7,0xb7,0xf7,0xdb,0x55,0x41,0x00,0xd0,0x1f,0x10,0x01,0xbb,0xff,
 0xef,0xff,0xdf,0x7f,0xfd,0xfe,0xff,0xbb,0x10,0xb5,0x04,0x74,0x45,0x54,0xff,
 0xfb,0xfb,0xef,0xfd,0xfa,0xaf,0xff,0xbf,0x6e,0x0b,0x2a,0x50,0x81,0x02,0x01,
 0xef,0xff,0xfe,0xfb,0xaf,0xef,0xff,0xfd,0xff,0xdb,0xaa,0x28,0x01,0x48,0x28,
 0x48,0xfb,0xff,0xff,0xff,0xfb,0xaa,0xfe,0xef,0x6f,0x57,0x55,0x25,0x04,0x00,
 0x82,0x04,0xff,0xde,0xff,0x7f,0x2f,0x01,0x6d,0xfb,0xfa,0xba,0x56,0xa5,0x20,
 0x29,0x10,0x50,0xbf,0xff,0x7f,0xff,0xab,0x48,0xd8,0xde,0xaf,0xd7,0xed,0x2e,
 0x05,0x00,0x81,0x04,0xed,0xf7,0xff,0xef,0x55,0x20,0xa1,0x55,0xb5,0x74,0x5f,
 0xb5,0x90,0x44,0x08,0x20,0xff,0x7d,0xf7,0xff,0x95,0x0a,0x44,0x55,0x55,0x55,
 0xf5,0xeb,0x27,0x10,0xa2,0x0a,0xb5,0xdf,0xff,0x7f,0xab,0x20,0x11,0x52,0x4a,
 0x42,0x02,0x5d,0xad,0x82,0x08,0x20,0xff,0xf6,0x7d,0xf7,0x55,0x5f,0x45,0x8a,
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



const unsigned char bitmap_scrollbar_background [] PROGMEM = {
  0x00, 0x40, 0x00, 0x40, 0x00, 0x40, 0x00, 0x40, 0x00, 0x40, 0x00, 0x40, 
  0x00, 0x40, 0x00, 0x40, 0x00, 0x40, 0x00, 0x40, 0x00, 0x40, 0x00, 0x40, 
  0x00, 0x40, 0x00, 0x40, 0x00, 0x40, 0x00, 0x40, 0x00, 0x40, 0x00, 0x40, 
  0x00, 0x40, 0x00, 0x40, 0x00, 0x40, 0x00, 0x40, 0x00, 0x40, 0x00, 0x40, 
  0x00, 0x40, 0x00, 0x40, 0x00, 0x40, 0x00, 0x40, 0x00, 0x40, 0x00, 0x40, 
  0x00, 0x40, 0x00, 0x00, };


const unsigned char FLAPPY[] PROGMEM =   {
  0x80,0x0f,0x00,0x70,0x12,0x00,0x08,0x21,0x00,0x04,0x51,0x00,0x02,0x51,0x00,
 0x3e,0x42,0x00,0x41,0xfc,0x00,0x41,0x03,0x01,0x3e,0xfd,0x00,0x04,0x42,0x00,
 0x18,0x3c,0x00,0xe0,0x03,0x00}; 


const unsigned char PONG[] PROGMEM =   {
  0x00,0x00,0x00,0x02,0x00,0x00,0x02,0x00,0x00,0x1a,0x00,0x00,0x1a,0x00,0x00,
 0x02,0x40,0x00,0x02,0x40,0x00,0x00,0x40,0x00,0x00,0x40,0x00,0x00,0x40,0x00,
 0x00,0x40,0x00,0x00,0x00,0x00}; 

const unsigned char CAMERA[] PROGMEM =   {
0x00,0x00,0x00,0xc0,0x07,0x00,0x40,0x04,0x00,0xff,0xff,0x01,0x01,0x00,0x01,
 0xc1,0x67,0x01,0x41,0x64,0x01,0x41,0x04,0x01,0x41,0x04,0x01,0xc1,0x07,0x01,
 0x01,0x00,0x01,0xff,0xff,0x01}; 


const unsigned char YOUTUBE[] PROGMEM =   {
0x00,0x00,0x00,0x00,0x00,0x00,0x30,0x00,0x00,0xf0,0x00,0x00,0xf0,0x03,0x00,
 0xf0,0x0f,0x00,0xf0,0x03,0x00,0xf0,0x00,0x00,0x30,0x00,0x00,0x00,0x00,0x00,
 0x00,0x00,0x00,0x00,0x00,0x00}; 


const unsigned char WIFI[] PROGMEM =   {
0x00,0x00,0x00,0xf0,0x0f,0x00,0x08,0x10,0x00,0xe4,0x27,0x00,0x12,0x48,0x00,
 0xc9,0x93,0x00,0x24,0x24,0x00,0x90,0x09,0x00,0x80,0x01,0x00,0x80,0x01,0x00,
 0x80,0x01,0x00,0x00,0x00,0x00}; 

const unsigned char* bitmap_icons[5] = {
  FLAPPY,
  PONG,
  CAMERA,
  YOUTUBE,
  WIFI
};


const int NUM_ITEMS = 5; // number of items in the list and also the number of screenshots and screenshots with QR codes (other screens)
const int MAX_ITEM_LENGTH = 20; // maximum characters for the item name

char menu_items [NUM_ITEMS] [MAX_ITEM_LENGTH] = {  // array with item names
  { "FLAPPY" }, 
  { "PONG" }, 
  { "CAMERA" }, 
  { "YOUTUBE" }, 
  { "WI-FI" }
 };


bool hasRun = false;


#define BUTTON_UP_PIN 2 // pin for UP button 
#define BUTTON_SELECT_PIN 13  // pin for SELECT button
#define BUTTON_DOWN_PIN 12 // pin for DOWN button

//#define DEMO_PIN 13 // pin for demo mode, use switch or wire to enable or disable demo mode, see more details below


int button_up_clicked = 0; // only perform action when button is clicked, and wait until another press
int button_select_clicked = 0; // same as above
int button_down_clicked = 0; // same as above

int item_selected = 0; // which item in the menu is selected

int item_sel_previous; // previous item - used in the menu screen to draw the item before the selected one
int item_sel_next; // next item - used in the menu screen to draw next item after the selected one

int current_screen = 0;   // 0 = menu, 1 = screenshot, 2 = qr

int demo_mode = 0; // when demo mode is set to 1, it automatically goes over all the screens, 0 = control menu with buttons
int demo_mode_state = 0; // demo mode state = which screen and menu item to display
int demo_mode_delay = 0; // demo mode delay = used to slow down the screen switching



void setup() {

Serial.begin(115200);


///////////////////////////////////////////////////////////////////////////
   display.init();

    //display.display();
    unsigned long start = millis();

    pinMode(UP_BUTTON, INPUT_PULLUP);
    pinMode(DOWN_BUTTON, INPUT_PULLUP);

    display.clear();
    //drawCourt();

    while(millis() - start < 2000);

    display.display();

    ball_update = millis();
    paddle_update = ball_update;
    display.flipScreenVertically();
////////////////////////////////////////////////////////////////


pinMode(13,INPUT_PULLUP); 
  //display.init();
  display.init();
  for(int i=0;i<4;i++)
  {
    zidx[i]=128+((i+1)*razmak);
    {prazan[i]=random(8,32);}
    }

////////////////////////////////////////////////////////////////////////////////////

 WRITE_PERI_REG(RTC_CNTL_BROWN_OUT_REG, 0); //disable brownout detector
 
  Serial.setDebugOutput(false);
  
  camera_config_t config;
  config.ledc_channel = LEDC_CHANNEL_0;
  config.ledc_timer = LEDC_TIMER_0;
  config.pin_d0 = Y2_GPIO_NUM;
  config.pin_d1 = Y3_GPIO_NUM;
  config.pin_d2 = Y4_GPIO_NUM;
  config.pin_d3 = Y5_GPIO_NUM;
  config.pin_d4 = Y6_GPIO_NUM;
  config.pin_d5 = Y7_GPIO_NUM;
  config.pin_d6 = Y8_GPIO_NUM;
  config.pin_d7 = Y9_GPIO_NUM;
  config.pin_xclk = XCLK_GPIO_NUM;
  config.pin_pclk = PCLK_GPIO_NUM;
  config.pin_vsync = VSYNC_GPIO_NUM;
  config.pin_href = HREF_GPIO_NUM;
  config.pin_sscb_sda = SIOD_GPIO_NUM;
  config.pin_sscb_scl = SIOC_GPIO_NUM;
  config.pin_pwdn = PWDN_GPIO_NUM;
  config.pin_reset = RESET_GPIO_NUM;
  config.xclk_freq_hz = 20000000;
  config.pixel_format = PIXFORMAT_JPEG; 
  
  if(psramFound()){
    config.frame_size = FRAMESIZE_UXGA;
    config.jpeg_quality = 10;
    config.fb_count = 2;
  } else {
    config.frame_size = FRAMESIZE_SVGA;
    config.jpeg_quality = 12;
    config.fb_count = 1;
  }
 // Camera init
  esp_err_t err = esp_camera_init(&config);
  if (err != ESP_OK) {
    Serial.printf("Camera init failed with error 0x%x", err);
    return;
  }


////////////////////////////beginning of menu setup //////////////////////////////////////////

  u8g2.setColorIndex(1);  // set the color to white
  u8g2.begin();
  u8g2.setBitmapMode(1);
  u8g2.setFont(u8g2_font_7x13B_tf);
  //Wire.begin(SCREEN_SDA, SCREEN_SCL);
  // define pins for buttons
  // INPUT_PULLUP means the button is HIGH when not pressed, and LOW when pressed
  // since it´s connected between some pin and GND
  pinMode(BUTTON_UP_PIN, INPUT_PULLUP); // up button
  pinMode(BUTTON_SELECT_PIN, INPUT_PULLUP); // select button
  pinMode(BUTTON_DOWN_PIN, INPUT_PULLUP); // down button

  u8g2.clearBuffer();
  u8g2.drawXBMP( 0, 0, 128, 64,FACE);
  u8g2.sendBuffer();
  
 WIFIAP();
////////////////////////////end of menu setup //////////////////////////////////////////
}


void loop() {


  if (current_screen == 0) { // MENU SCREEN

      // up and down buttons only work for the menu screen
      if ((digitalRead(BUTTON_UP_PIN) == LOW) && (button_up_clicked == 0)) { // up button clicked - jump to previous menu item
        item_selected = item_selected - 1; // select previous item
        button_up_clicked = 1; // set button to clicked to only perform the action once
        if (item_selected < 0) { // if first item was selected, jump to last item
          item_selected = NUM_ITEMS-1;
        }
      }
      else if ((digitalRead(BUTTON_DOWN_PIN) == LOW) && (button_down_clicked == 0)) { // down button clicked - jump to next menu item
        item_selected = item_selected + 1; // select next item
        button_down_clicked = 1; // set button to clicked to only perform the action once
        if (item_selected >= NUM_ITEMS) { // last item was selected, jump to first menu item
          item_selected = 0;
          }
      } 

      if ((digitalRead(BUTTON_UP_PIN) == HIGH) && (button_up_clicked == 1)) { // unclick 
        button_up_clicked = 0;
      }
      if ((digitalRead(BUTTON_DOWN_PIN) == HIGH) && (button_down_clicked == 1)) { // unclick
        button_down_clicked = 0;
      }

  }


  if ((digitalRead(BUTTON_SELECT_PIN) == LOW) && (button_select_clicked == 0)) { // select button clicked, jump between screens
     button_select_clicked = 1; // set button to clicked to only perform the action once
     if (current_screen == 0){

    //(*FUNCTION[item_selected])();
        current_screen = 1;
        } // menu items screen --> screenshots screen
     //else if (current_screen == 1) {current_screen = 2;} // screenshots screen --> qr codes screen
     
     else {current_screen = 0;} // qr codes screen --> menu items screen
  }
  if ((digitalRead(BUTTON_SELECT_PIN) == HIGH) && (button_select_clicked == 1)) { // unclick 
    button_select_clicked = 0;
  }

  // set correct values for the previous and next items
  item_sel_previous = item_selected - 1;
  if (item_sel_previous < 0) {item_sel_previous = NUM_ITEMS - 1;} // previous item would be below first = make it the last
  item_sel_next = item_selected + 1;  
  if (item_sel_next >= NUM_ITEMS) {item_sel_next = 0;} // next item would be after last = make it the first


  u8g2.clearBuffer(); // required for page drawing mode for u8g2 library
  // u8g2.firstPage();
  // do {
    if (current_screen == 0) { // MENU SCREEN
      //u8g2.firstPage();
       //do {
      // selected item background
      u8g2.drawRFrame(0, 22, 120, 20,7);

      // draw previous item as icon + label
      u8g2.setFont(u8g2_font_7x13B_tf);
      u8g2.drawStr(25, 17, menu_items[item_sel_previous]); 
      u8g2.drawXBMP( 4, 3, 17, 12, bitmap_icons[item_sel_previous]);          

      // draw selected item as icon + label in bold font
      u8g2.setFont(u8g2_font_7x13B_tf);  
      u8g2.drawStr(25, 38, menu_items[item_selected]);   
      u8g2.drawXBMP( 4, 25, 17, 12, bitmap_icons[item_selected]);     

      // draw next item as icon + label
      u8g2.setFont(u8g2_font_7x13B_tf);   
      u8g2.drawStr(25, 59, menu_items[item_sel_next]);   
      u8g2.drawXBMP( 4, 47, 17, 12, bitmap_icons[item_sel_next]);  

      //draw scrollbar background
      u8g2.drawXBMP(128-8, 0, 8, 64, bitmap_scrollbar_background);

      // draw scrollbar handle
      u8g2.drawBox(125, 64/NUM_ITEMS * item_selected, 3, 64/NUM_ITEMS); 

    } 


    while (current_screen == 1) { // SCREENSHOTS SCREEN
      (*FUNCTION[item_selected])();

    }
   
  u8g2.sendBuffer(); // send buffer from RAM to display controller

}
 


void FLAPPY1() {
 gamechflap();   
}

void PONG1() {
  gamechpong();  
}

void CAMERA1() {
  if(!hasRun){
  
  startCameraServer();  
  hasRun = true;
            }
}

void YOUTUBE1() {
  u8g2.clearBuffer();
  u8g2.drawXBMP( 0, 0, 128, 64,FACE);
  u8g2.sendBuffer();  
}

void WIFI1() {
  u8g2.clearBuffer();
  u8g2.drawXBMP( 0, 0, 128, 64,FACE);
  u8g2.sendBuffer();  
}

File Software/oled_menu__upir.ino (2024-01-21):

// simple project using Arduino UNO and 128x64 OLED Display to display a menu
// created by upir, 2022
// youtube channel: https://www.youtube.com/upir_upir

// YOUTUBE VIDEO: https://youtu.be/HVHVkKt-ldc

// links from the video:
// Flipper Zero menu - https://docs.flipperzero.one/basics/control#M5BZO
// WOKWI start project progress bar - https://wokwi.com/projects/300867986768527882
// image2cpp - https://javl.github.io/image2cpp/
// 128x64 SSD1306 OLED Display: https://s.click.aliexpress.com/e/_DCKdvnh
// Transparent OLED display: https://s.click.aliexpress.com/e/_Dns6eLz
// Arduino UNO: https://s.click.aliexpress.com/e/_AXDw1h
// Arduino UNO MINI: https://store.arduino.cc/products/uno-mini-le
// Big OLED Display: https://s.click.aliexpress.com/e/_ADL0T9
// Arduino breadboard prototyping shield: https://s.click.aliexpress.com/e/_ApbCwx
// u8g fonts (fonts available for u8g library): https://nodemcu-build.com/u8g-fonts.php
// u8g documentation: https://github.com/olikraus/u8glib/wiki/userreference
// Photopea (online Photoshop-like tool): https://www.photopea.com/
// image2cpp (convert images into C code): https://javl.github.io/image2cpp/
// Push buttons - https://s.click.aliexpress.com/e/_DmXS8B9

// Related videos:
// Arduino Parking Sensor - https://youtu.be/sEWw087KOj0
// Turbo pressure gauge with Arduino and OLED display - https://youtu.be/JXmw1xOlBdk
// Arduino Car Cluster with OLED Display - https://youtu.be/El5SJelwV_0
// Knob over OLED Display - https://youtu.be/SmbcNx7tbX8
// Arduino + OLED = 3D ? - https://youtu.be/kBAcaA7NAlA
// Arduino OLED Gauge - https://youtu.be/xI6dXTA02UQ
// Smaller & Faster Arduino - https://youtu.be/4GfPQoIRqW8



#include "U8glib.h"

U8GLIB_SSD1306_128X64 u8g(U8G_I2C_OPT_DEV_0 | U8G_I2C_OPT_NO_ACK | U8G_I2C_OPT_FAST); // Fast I2C / TWI
// U8GLIB_SSD1306_128X64 u8g(13, 11, 8, 9, 10); // SPI connection
// for SPI connection, use this wiring:
// GND > GND
// VCC > 5V
// SCL > 13
// SDA > 11
// RES > 10
// DC > 9
// CS > 8



// all the arrays below are generated from images using image2cpp website
// scroll down to see the actual code

const unsigned char upir_logo [] PROGMEM = {  // this is another way how to define images, using binary notation
B00010101,  B11010111,
B00010101,  B01000101,
B00010101,  B10010110,
B00011001,  B00010101     
};

// 'icon_3dcube', 16x16px
const unsigned char bitmap_icon_3dcube [] PROGMEM = {
  0x00, 0x00, 0x01, 0x80, 0x07, 0x60, 0x19, 0x18, 0x61, 0x06, 0x51, 0x0a, 0x45, 0xa2, 0x41, 0x02, 
  0x45, 0x22, 0x41, 0x02, 0x45, 0xa2, 0x51, 0x0a, 0x61, 0x06, 0x19, 0x18, 0x07, 0x60, 0x01, 0x80
};
// 'icon_battery', 16x16px
const unsigned char bitmap_icon_battery [] PROGMEM = {
  0x00, 0x00, 0x00, 0x00, 0x00, 0x00, 0x00, 0x00, 0x3f, 0xf8, 0x40, 0x04, 0x5b, 0x66, 0x5b, 0x66, 
  0x5b, 0x66, 0x40, 0x04, 0x3f, 0xf8, 0x00, 0x00, 0x00, 0x00, 0x00, 0x00, 0x00, 0x00, 0x00, 0x00
};
// 'icon_dashboard', 16x16px
const unsigned char bitmap_icon_dashboard [] PROGMEM = {
  0x07, 0xe0, 0x18, 0x18, 0x21, 0x24, 0x50, 0x02, 0x48, 0x0a, 0x84, 0x01, 0x83, 0x81, 0xa2, 0x45, 
  0x82, 0x41, 0x81, 0x81, 0xa0, 0x05, 0x40, 0x02, 0x4b, 0xd2, 0x23, 0xc4, 0x18, 0x18, 0x07, 0xe0
};
// 'icon_fireworks', 16x16px
const unsigned char bitmap_icon_fireworks [] PROGMEM = {
  0x00, 0x00, 0x00, 0x08, 0x00, 0x94, 0x10, 0x08, 0x10, 0x00, 0x6c, 0x00, 0x10, 0x10, 0x10, 0x10, 
  0x00, 0x00, 0x00, 0xc6, 0x00, 0x00, 0x00, 0x10, 0x04, 0x10, 0x0a, 0x00, 0x04, 0x00, 0x00, 0x00
};
// 'icon_gps_speed', 16x16px
const unsigned char bitmap_icon_gps_speed [] PROGMEM = {
  0x00, 0x00, 0x03, 0xf0, 0x00, 0x08, 0x01, 0xe4, 0x00, 0x12, 0x00, 0xca, 0x06, 0x2a, 0x07, 0x2a, 
  0x07, 0x8a, 0x07, 0xc2, 0x07, 0xc0, 0x0a, 0x00, 0x1f, 0x00, 0x20, 0x80, 0x7f, 0xc0, 0x00, 0x00
};
// 'icon_knob_over_oled', 16x16px
const unsigned char bitmap_icon_knob_over_oled [] PROGMEM = {
  0x00, 0x00, 0x1f, 0xf0, 0x13, 0x50, 0x1b, 0xb0, 0x11, 0x50, 0x1f, 0xf0, 0x03, 0x80, 0x01, 0x00, 
  0x00, 0x00, 0x09, 0x20, 0x49, 0x24, 0x20, 0x08, 0x00, 0x01, 0x80, 0x02, 0x00, 0x00, 0x00, 0x00
};
// 'icon_parksensor', 16x16px
const unsigned char bitmap_icon_parksensor [] PROGMEM = {
  0x00, 0x00, 0x00, 0x00, 0x00, 0x00, 0xfc, 0x00, 0x22, 0x00, 0x25, 0x00, 0xf9, 0x00, 0x00, 0x81, 
  0x0c, 0x85, 0x12, 0x95, 0xd2, 0x95, 0x0c, 0x05, 0x00, 0x01, 0x00, 0x00, 0x00, 0x00, 0x00, 0x00
};
// 'icon_turbo', 16x16px
const unsigned char bitmap_icon_turbo [] PROGMEM = {
  0x00, 0x0e, 0x07, 0xf1, 0x18, 0x01, 0x20, 0x01, 0x40, 0x01, 0x43, 0xf1, 0x84, 0x4e, 0x8a, 0xa0, 
  0x89, 0x22, 0x8a, 0xa2, 0x84, 0x42, 0x43, 0x84, 0x40, 0x04, 0x20, 0x08, 0x18, 0x30, 0x07, 0xc0
};

// Array of all bitmaps for convenience. (Total bytes used to store images in PROGMEM = 384)
const unsigned char* bitmap_icons[8] = {
  bitmap_icon_3dcube,
  bitmap_icon_battery,
  bitmap_icon_dashboard,
  bitmap_icon_fireworks,
  bitmap_icon_gps_speed,
  bitmap_icon_knob_over_oled,
  bitmap_icon_parksensor,
  bitmap_icon_turbo
};
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

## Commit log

2024-10-29 added google sheets link and csv file link for the BOM/PARTS LIST
2024-10-29 added kicad design files and pdf showing schematic
    [ESP32CAM.kicad_pcb, ESP32CAM.kicad_sch]
